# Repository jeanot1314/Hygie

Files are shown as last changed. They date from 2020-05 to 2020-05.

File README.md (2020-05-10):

# Hygie
A device to better follow your body's reactions. Hygie helps you to understand the evolution of symptoms that can affect you on daily basis

Created by Jean Perardel

Full Tutoriel on [Hackster](https://www.hackster.io/jeanperardel/hygie-better-follow-and-understand-your-menopause-fa8663)

Presentation Video on [Lab_1314](https://www.youtube.com/watch?v=uz1osdS2IEg)

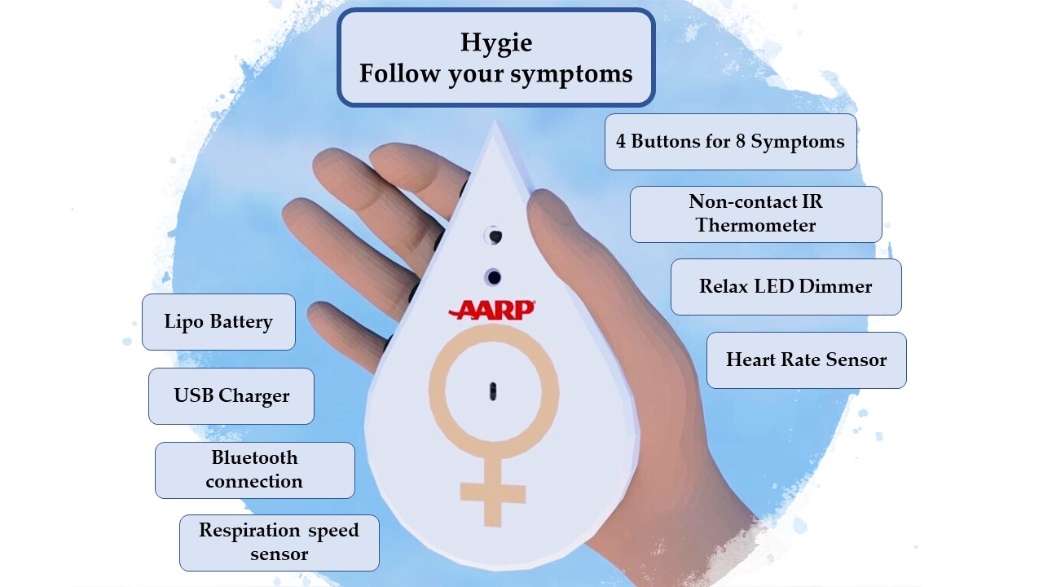
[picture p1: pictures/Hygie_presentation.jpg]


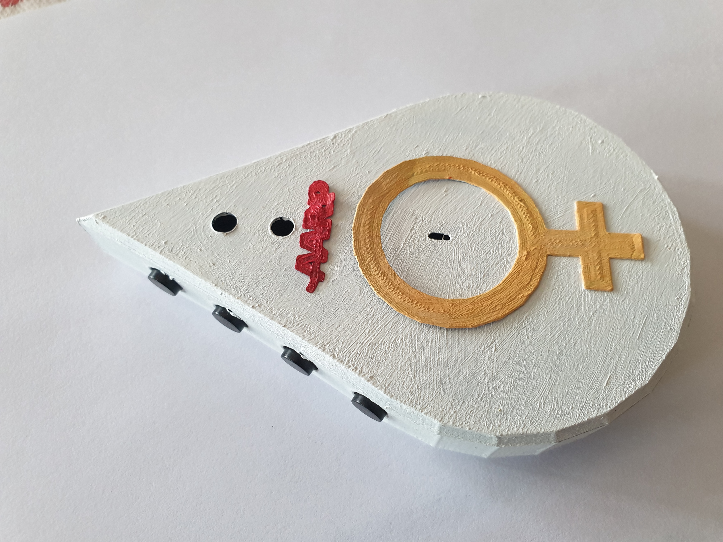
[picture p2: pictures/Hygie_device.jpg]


## Storie

The Hygie project has been designed to help women listen to and follow their bodies during this complicated period. To do this, it offers a simple and evolving interface that allows the different symptoms to be traced over time. The small device can easily fit into a coat pocket or handbag to accompany you discreetly everywhere.

Hygieia (Hygie in French) was one of the daughters of the God of medecine Asclepius in the Greek mythology. she was the goddess/personification of health.

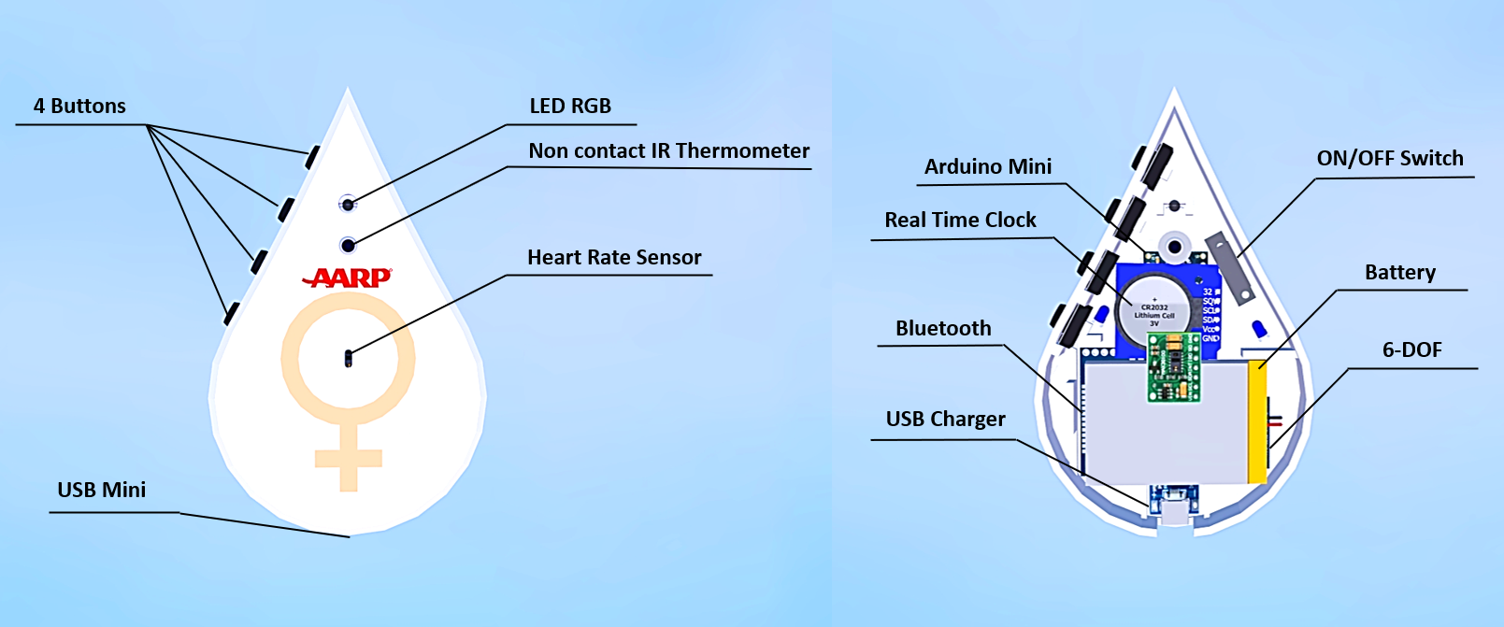
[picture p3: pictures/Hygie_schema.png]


The 4 buttons on the top allow you to trace the symptoms over time. Each of them must be associated with one (single click) or two (double click) symptoms according to the need and therefore recurrence for its user.

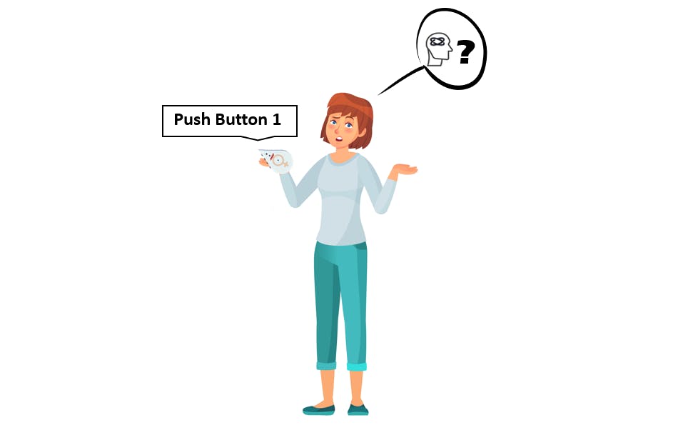
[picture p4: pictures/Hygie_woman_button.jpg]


Here is a configuration example :

Button 1 (single click) : Hot Flashes

Button 1 (double click) : Fatigue

Button 2 (single click) : Hair Loss

Button 2 (double click) : Incontinence

Button 3 (single click) : Change in odor

Button 4 (single click) : Mood Swings

Pressing these buttons at the onset of symptoms will allow you to trace the event over time and better understand their recurrence. Using Hygie for a period of time will thus generate graphs on the mobile application.

These data are also associated in tabular form with simple interpretations such as "The phenomenon of fatigue is particularly present after a meal" or "Gum problems" are often associated with "Breast Soreness".

## Build the device

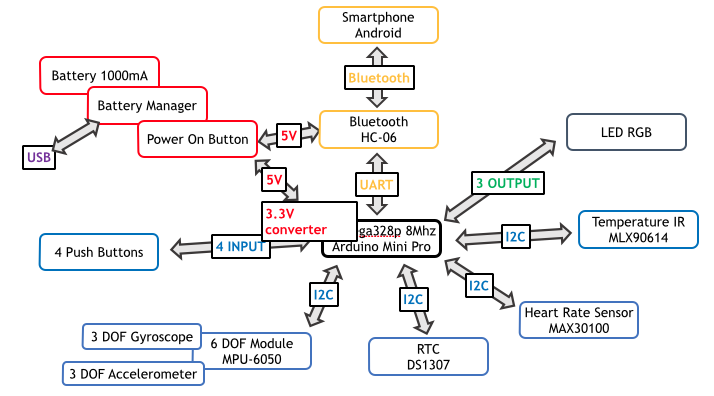
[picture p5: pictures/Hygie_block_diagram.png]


## Hardware

Image of Pi

The most important thing to remember here is that almost whole the system works in 3.3V. This forced me to carefully select the components (at first I wanted to use WS2812 RGB LEDs, but they are rather unstable in 3.3V so I had to remove them... too bad for the color rendering!).

At first, I thought the 3.6V Bluetooth would work on the 3.7V battery, but it seemed unstable... So I had to add a BOOST at the end to power only this part with 5V and step down everything else with the embedded regulator on the Arduino Pro Mini. I will probably change the Bluetooth board on the next version to remove the BOOST and have the all system working at 3.3V. This will also be a good occasion to move to BLE.

Another interesting part will be to develop small boards with MOSFETs to cut the power supply of unused modules. Indeed, this system uses some functionality only very occasionally. It is therefore a pity that a module like the MPU6050 consumes power all the time.

## Software

Arduino development on a Atmega328p target running at 8Mhz (FIO mode) 

Image of Pi

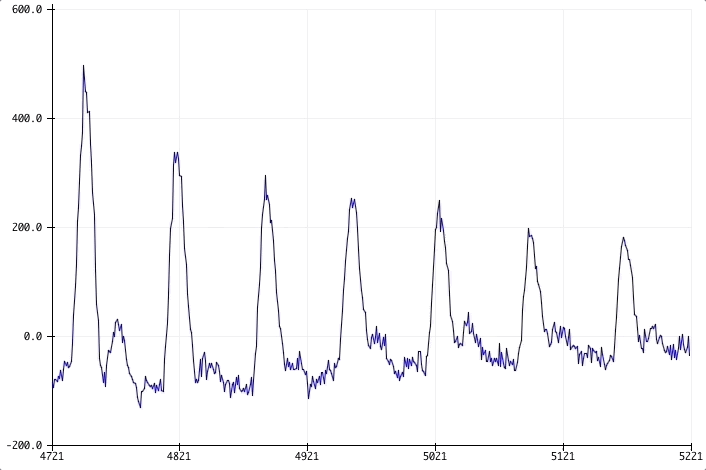
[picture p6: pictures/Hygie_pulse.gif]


## 3D design

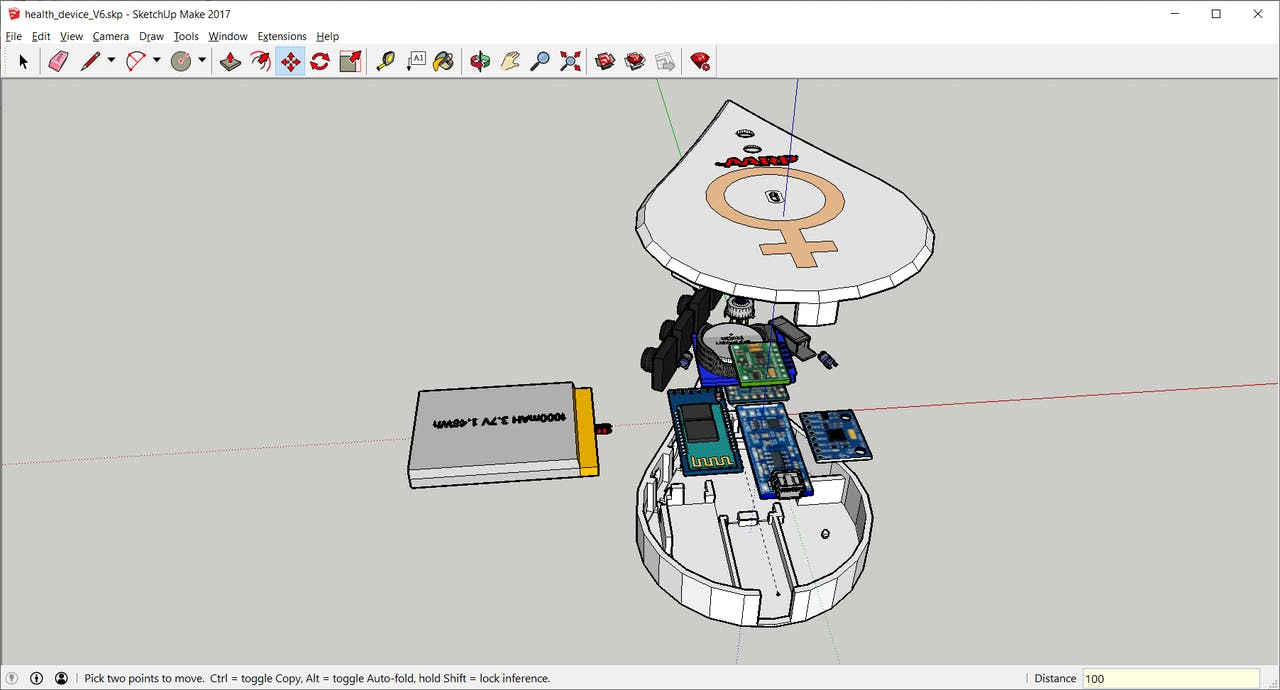
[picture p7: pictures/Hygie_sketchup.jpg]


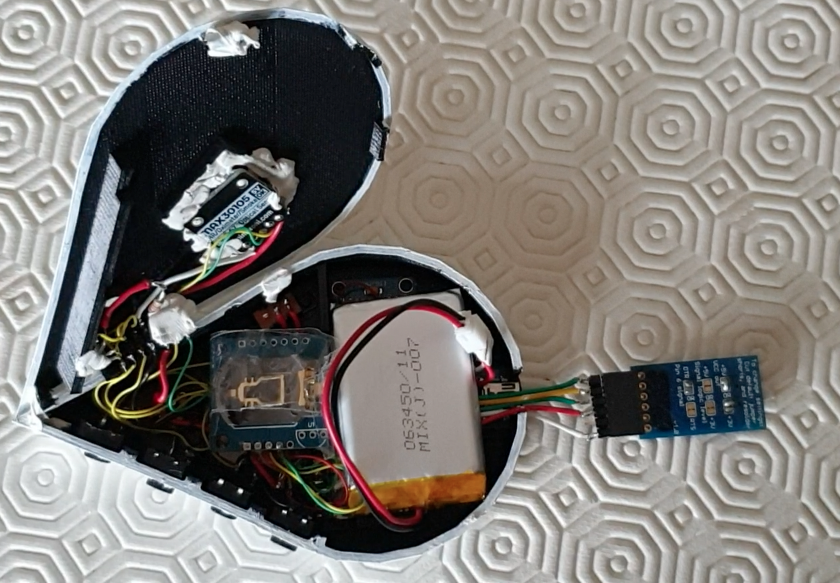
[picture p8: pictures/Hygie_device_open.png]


## Phone Graph (MIT App Inventor)

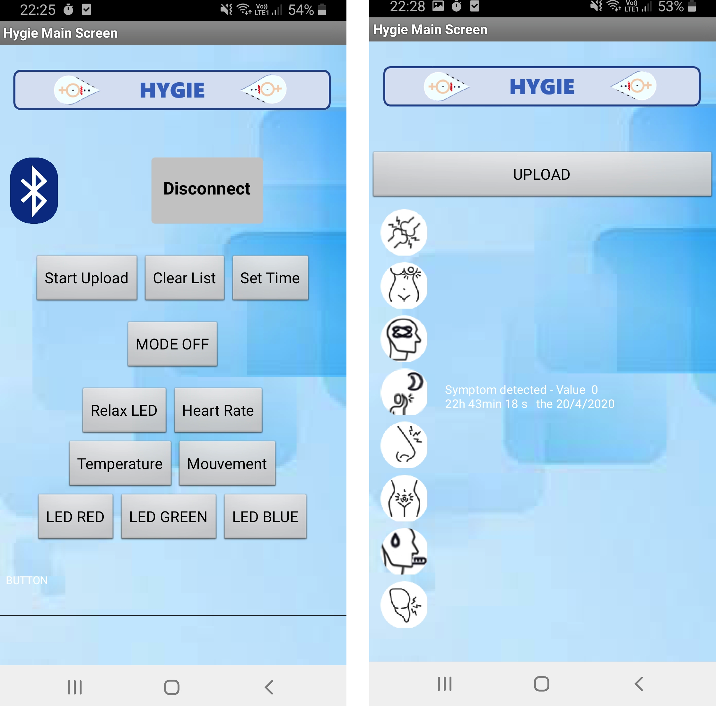
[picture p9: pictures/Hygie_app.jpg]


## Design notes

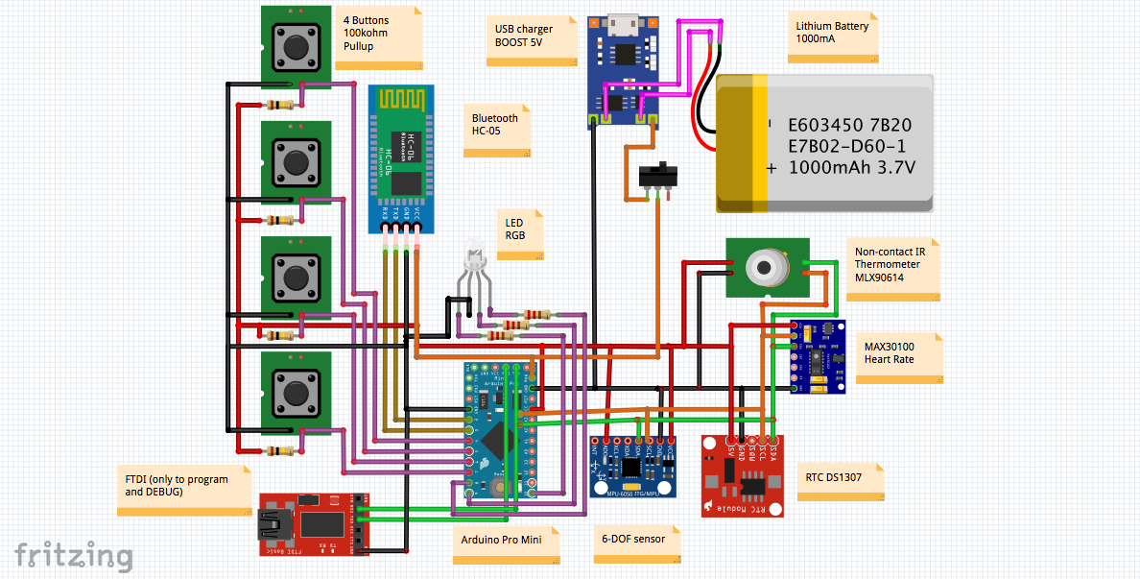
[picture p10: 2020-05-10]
pictures/Hygie_hardware.png

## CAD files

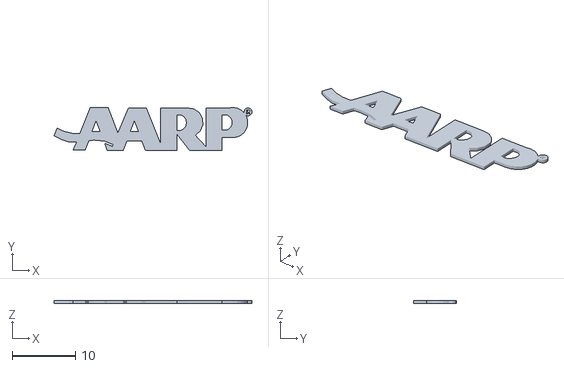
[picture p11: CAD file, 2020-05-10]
3D/health_device_V8_logo.stl
31.3 x 6.82 x 0.4

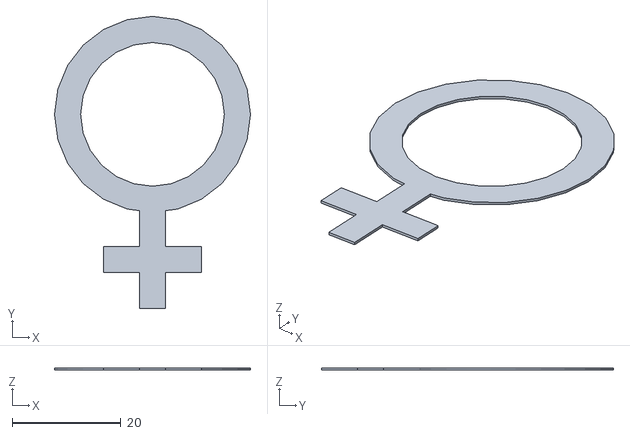
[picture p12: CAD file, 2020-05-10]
3D/health_device_V8_woman.stl
36.0 x 53.7 x 0.4

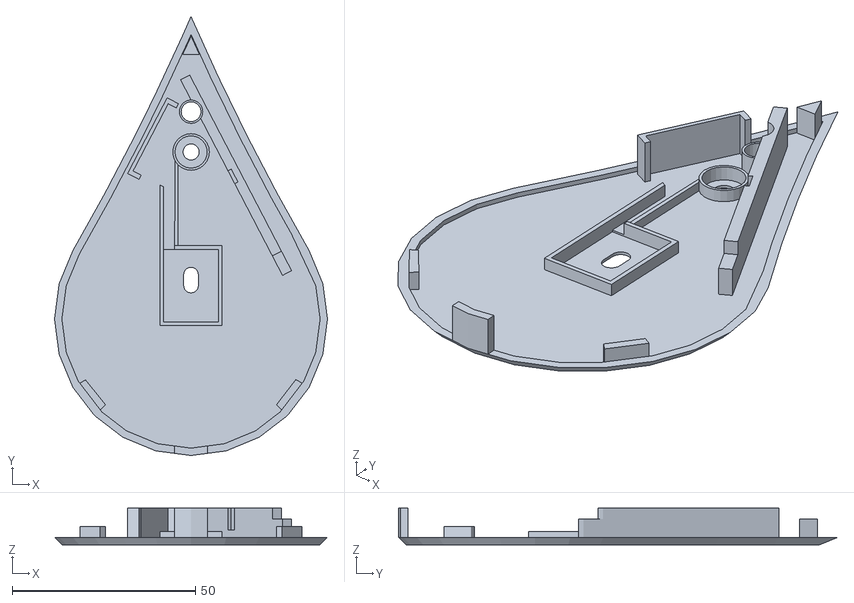
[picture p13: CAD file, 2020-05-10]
3D/health_device_V8_TOP.stl
74.6 x 119.9 x 10.0

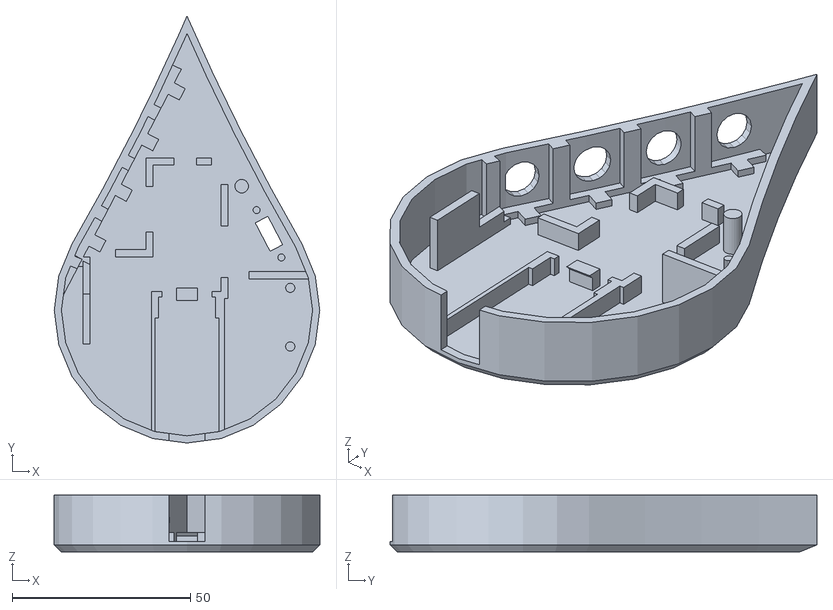
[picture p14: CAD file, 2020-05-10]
3D/health_device_V8.stl
74.6 x 119.9 x 16.0

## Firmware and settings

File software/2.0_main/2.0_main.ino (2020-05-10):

/*
 * Arduino code made by Jean Perardel
 * Project Hygie
 * 
 * 04 mai 2020
 */


#include <Wire.h>
#include <avr/interrupt.h>
#include <avr/pgmspace.h>
#include <SoftwareSerial.h>
#include <Adafruit_MLX90614.h>
// Temporary replacement from MAX30100 to MAX30105 because of supply
#include "MAX30100.h"
//#include "MAX30105.h"
#include "heartRate.h"
#include "RTCDS1307.h"
#include <EEPROM.h>

// MPU6050 6-DOF Sensor
#define MPU_ADDR 0x69
#define MEM_START_ADDR 0x6E
#define MEM_R_W 0x6F

// EEPROM cluster definition
#define EEPROM_CLUSTER_SIZE 8

// BLUETOOTH BUFFER SIZE
#define BLUETOOTH_BUFFER_SIZE 32

// define the time (in loop) necessary to consider a short and a long push button
#define Min_Time_Short_Push_Button 2
#define Min_Time_Long_Push_Button 15

// Reset the main counter at :
#define MAX_COUNTER 0xFFFF

// Definition of pseudo real time. Frequency will define the number of time the program
//enter the function on MAX_COUNTER number
#define Buttons_FREQUENCY 128
#define Buttons_FREQUENCY_READ_PER_CYCLE cpt%((MAX_COUNTER/Buttons_FREQUENCY)+1)
#define MAX30100_FREQUENCY 256
#define MAX30100_FREQUENCY_READ_PER_CYCLE cpt%((MAX_COUNTER/MAX30100_FREQUENCY)+1)
#define MLX90614_FREQUENCY 1
#define MLX90614_FREQUENCY_READ_PER_CYCLE cpt%((MAX_COUNTER/MLX90614_FREQUENCY)+1)
#define MPU6050_FREQUENCY 128
#define MPU6050_FREQUENCY_READ_PER_CYCLE cpt%((MAX_COUNTER/MPU6050_FREQUENCY)+1)
#define DS1307_FREQUENCY 1
#define DS1307_FREQUENCY_READ_PER_CYCLE cpt%((MAX_COUNTER/DS1307_FREQUENCY)+1)
#define HC06_FREQUENCY 128
#define HC06_FREQUENCY_READ_PER_CYCLE cpt%((MAX_COUNTER/HC06_FREQUENCY)+1)
#define Serial_FREQUENCY 128
#define Serial_FREQUENCY_READ_PER_CYCLE cpt%((MAX_COUNTER/Serial_FREQUENCY)+1)
#define DimLED_FREQUENCY 64
#define DimLED_FREQUENCY_READ_PER_CYCLE cpt%((MAX_COUNTER/DimLED_FREQUENCY)+1)
#define DebugLED_FREQUENCY 1
#define DebugLED_FREQUENCY_READ_PER_CYCLE cpt%((MAX_COUNTER/DebugLED_FREQUENCY)+1)
#define LEDPushButton_FREQUENCY 16
#define LEDPushButton_FREQUENCY_READ_PER_CYCLE cpt%((MAX_COUNTER/LEDPushButton_FREQUENCY)+1)

//----------------------- Variable for MPU6050 6-DOF Sensor-----------------------------
long lastRead = 0;
byte processed_packet[8];
byte received_packet[50];
byte temp = 0;
byte fifoCountL = 0;
byte fifoCountL2 = 0;
byte packetCount = 0x00;
boolean longPacket = false;
boolean firstPacket = true;
float q[4];

//This 3D array contains the default DMP memory bank binary that gets loaded during initialization.
//In the Invensense UC3-A3 firmware this is uploaded in 128 byte tranmissions, but the Arduino Wire
//library only supports 32 byte transmissions, including the register address to which you're writing,
//so I broke it up into 16 byte transmission payloads which are sent in the dmp_init() function below.
//
//This was reconstructed from observed I2C traffic generated by the UC3-A3 demo code, and not extracted
//directly from that code. That is true of all transmissions in this sketch, and any documentation has
//been added after the fact by referencing the Invensense code.

// this tab takes 6% of memory program storage 
unsigned const char dmpMem[8][16][16] PROGMEM = {
  {
    {0xFB, 0x00, 0x00, 0x3E, 0x00, 0x0B, 0x00, 0x36, 0x00, 0x01, 0x00, 0x02, 0x00, 0x03, 0x00, 0x00},
    {0x00, 0x65, 0x00, 0x54, 0xFF, 0xEF, 0x00, 0x00, 0xFA, 0x80, 0x00, 0x0B, 0x12, 0x82, 0x00, 0x01},
    {0x00, 0x02, 0x00, 0x00, 0x00, 0x00, 0x00, 0x00, 0x00, 0x00, 0x00, 0x00, 0x00, 0x00, 0x00, 0x00},
    {0x00, 0x28, 0x00, 0x00, 0xFF, 0xFF, 0x45, 0x81, 0xFF, 0xFF, 0xFA, 0x72, 0x00, 0x00, 0x00, 0x00},
    {0x00, 0x00, 0x03, 0xE8, 0x00, 0x00, 0x00, 0x01, 0x00, 0x01, 0x7F, 0xFF, 0xFF, 0xFE, 0x80, 0x01},
    {0x00, 0x1B, 0x00, 0x00, 0x00, 0x00, 0x00, 0x00, 0x00, 0x00, 0x00, 0x00, 0x00, 0x00, 0x00, 0x00},
    {0x00, 0x3E, 0x03, 0x30, 0x40, 0x00, 0x00, 0x00, 0x02, 0xCA, 0xE3, 0x09, 0x3E, 0x80, 0x00, 0x00},
    {0x20, 0x00, 0x00, 0x00, 0x00, 0x00, 0x00, 0x00, 0x40, 0x00, 0x00, 0x00, 0x60, 0x00, 0x00, 0x00},
    {0x41, 0xFF, 0x00, 0x00, 0x00, 0x00, 0x0B, 0x2A, 0x00, 0x00, 0x16, 0x55, 0x00, 0x00, 0x21, 0x82},
    {0xFD, 0x87, 0x26, 0x50, 0xFD, 0x80, 0x00, 0x00, 0x00, 0x1F, 0x00, 0x00, 0x00, 0x05, 0x80, 0x00},
    {0x00, 0x00, 0x00, 0x00, 0x00, 0x01, 0x00, 0x00, 0x00, 0x02, 0x00, 0x00, 0x00, 0x03, 0x00, 0x00},
    {0x40, 0x00, 0x00, 0x00, 0x00, 0x00, 0x04, 0x6F, 0x00, 0x02, 0x65, 0x32, 0x00, 0x00, 0x5E, 0xC0},
    {0x40, 0x00, 0x00, 0x00, 0x00, 0x00, 0x00, 0x00, 0x00, 0x00, 0x00, 0x00, 0x00, 0x00, 0x00, 0x00},
    {0xFB, 0x8C, 0x6F, 0x5D, 0xFD, 0x5D, 0x08, 0xD9, 0x00, 0x7C, 0x73, 0x3B, 0x00, 0x6C, 0x12, 0xCC},
    {0x32, 0x00, 0x13, 0x9D, 0x32, 0x00, 0xD0, 0xD6, 0x32, 0x00, 0x08, 0x00, 0x40, 0x00, 0x01, 0xF4},
    {0xFF, 0xE6, 0x80, 0x79, 0x02, 0x00, 0x00, 0x00, 0x00, 0x00, 0xD0, 0xD6, 0x00, 0x00, 0x27, 0x10}
  },
  {
    {0xFB, 0x00, 0x00, 0x00, 0x40, 0x00, 0x00, 0x00, 0x00, 0x00, 0x00, 0x00, 0x00, 0x00, 0x00, 0x00},
    {0x00, 0x00, 0x00, 0x01, 0x00, 0x00, 0x00, 0x00, 0x00, 0x00, 0x01, 0x00, 0x01, 0x00, 0x00, 0x00},
    {0x00, 0x00, 0xFA, 0x36, 0xFF, 0xBC, 0x30, 0x8E, 0x00, 0x05, 0xFB, 0xF0, 0xFF, 0xD9, 0x5B, 0xC8},
    {0xFF, 0xD0, 0x9A, 0xBE, 0x00, 0x00, 0x10, 0xA9, 0xFF, 0xF4, 0x1E, 0xB2, 0x00, 0xCE, 0xBB, 0xF7},
    {0x00, 0x00, 0x00, 0x01, 0x00, 0x00, 0x00, 0x04, 0x00, 0x02, 0x00, 0x02, 0x02, 0x00, 0x00, 0x0C},
    {0xFF, 0xC2, 0x80, 0x00, 0x00, 0x01, 0x80, 0x00, 0x00, 0xCF, 0x80, 0x00, 0x40, 0x00, 0x00, 0x00},
    {0x00, 0x00, 0x00, 0x01, 0x00, 0x00, 0x00, 0x00, 0x00, 0x00, 0x06, 0x00, 0x00, 0x00, 0x00, 0x14},
    {0x00, 0x00, 0x00, 0x00, 0x00, 0x00, 0x00, 0x00, 0x00, 0x00, 0x00, 0x00, 0x00, 0x00, 0x00, 0x00},
    {0x00, 0x00, 0x00, 0x00, 0x00, 0x00, 0x00, 0x00, 0x00, 0x00, 0x00, 0x00, 0x00, 0x00, 0x00, 0x00},
    {0x00, 0x00, 0x00, 0x00, 0x00, 0x00, 0x00, 0x00, 0x00, 0x00, 0x00, 0x00, 0x00, 0x00, 0x00, 0x00},
    {0x00, 0x00, 0x00, 0x00, 0x03, 0x3F, 0x68, 0xB6, 0x79, 0x35, 0x28, 0xBC, 0xC6, 0x7E, 0xD1, 0x6C},
    {0x80, 0x00, 0x00, 0x00, 0x40, 0x00, 0x00, 0x00, 0x00, 0x00, 0xB2, 0x6A, 0x00, 0x00, 0x00, 0x00},
    {0x00, 0x00, 0x00, 0x00, 0x00, 0x00, 0x00, 0x00, 0x00, 0x00, 0x3F, 0xF0, 0x00, 0x00, 0x00, 0x30},
    {0x00, 0x00, 0x00, 0x00, 0x00, 0x00, 0x00, 0x00, 0x00, 0x00, 0x00, 0x00, 0x00, 0x00, 0x00, 0x00},
    {0x00, 0x00, 0x00, 0x00, 0x00, 0x00, 0x00, 0x00, 0x00, 0x00, 0x00, 0x00, 0x00, 0x00, 0x00, 0x00},
    {0x00, 0x00, 0x25, 0x4D, 0x00, 0x2F, 0x70, 0x6D, 0x00, 0x00, 0x05, 0xAE, 0x00, 0x0C, 0x02, 0xD0}
  },
  {
    {0x00, 0x00, 0x00, 0x00, 0x00, 0x65, 0x00, 0x54, 0xFF, 0xEF, 0x00, 0x00, 0x00, 0x00, 0x00, 0x00},
    {0x00, 0x00, 0x01, 0x00, 0x00, 0x44, 0x00, 0x00, 0x00, 0x00, 0x0C, 0x00, 0x00, 0x00, 0x01, 0x00},
    {0x00, 0x00, 0x00, 0x00, 0x00, 0x65, 0x00, 0x00, 0x00, 0x54, 0x00, 0x00, 0xFF, 0xEF, 0x00, 0x00},
    {0x00, 0x00, 0x00, 0x00, 0x00, 0x00, 0x00, 0x00, 0x00, 0x00, 0x00, 0x00, 0x00, 0x00, 0x00, 0x00},
    {0x40, 0x00, 0x00, 0x00, 0x00, 0x00, 0x00, 0x00, 0x00, 0x00, 0x00, 0x00, 0x00, 0x00, 0x00, 0x00},
    {0x40, 0x00, 0x00, 0x00, 0x00, 0x00, 0x00, 0x00, 0x00, 0x00, 0x00, 0x00, 0x00, 0x00, 0x00, 0x00},
    {0x00, 0x00, 0x00, 0x01, 0x00, 0x00, 0x00, 0x02, 0x00, 0x00, 0x00, 0x00, 0x00, 0x00, 0x00, 0x00},
    {0x00, 0x00, 0x00, 0x00, 0x00, 0x00, 0x00, 0x00, 0x00, 0x00, 0x00, 0x00, 0x00, 0x00, 0x00, 0x00},
    {0x00, 0x00, 0x00, 0x00, 0x00, 0x00, 0x00, 0x00, 0x00, 0x00, 0x00, 0x00, 0x00, 0x00, 0x00, 0x00},
    {0x00, 0x1B, 0x00, 0x00, 0x00, 0x00, 0x00, 0x00, 0x00, 0x00, 0x00, 0x00, 0x00, 0x00, 0x00, 0x00},
    {0x00, 0x00, 0x00, 0x00, 0x00, 0x00, 0x00, 0x00, 0x00, 0x00, 0x00, 0x00, 0x00, 0x00, 0x00, 0x00},
    {0x00, 0x00, 0x00, 0x00, 0x00, 0x00, 0x00, 0x00, 0x00, 0x00, 0x00, 0x00, 0x40, 0x00, 0x00, 0x00},
    {0x00, 0x1B, 0x00, 0x00, 0x00, 0x00, 0x00, 0x00, 0x00, 0x00, 0x00, 0x00, 0x00, 0x00, 0x00, 0x00},
    {0x00, 0x00, 0x00, 0x00, 0x00, 0x00, 0x00, 0x00, 0x00, 0x00, 0x00, 0x00, 0x00, 0x00, 0x00, 0x00},
    {0x00, 0x00, 0x00, 0x00, 0x00, 0x00, 0x00, 0x00, 0x00, 0x00, 0x00, 0x00, 0x00, 0x00, 0x00, 0x00},
    {0x00, 0x00, 0x00, 0x00, 0x00, 0x00, 0x00, 0x00, 0x00, 0x00, 0x00, 0x00, 0x00, 0x00, 0x00, 0x00}
  },
  {
    {0xD8, 0xDC, 0xBA, 0xA2, 0xF1, 0xDE, 0xB2, 0xB8, 0xB4, 0xA8, 0x81, 0x91, 0xF7, 0x4A, 0x90, 0x7F},
    {0x91, 0x6A, 0xF3, 0xF9, 0xDB, 0xA8, 0xF9, 0xB0, 0xBA, 0xA0, 0x80, 0xF2, 0xCE, 0x81, 0xF3, 0xC2},
    {0xF1, 0xC1, 0xF2, 0xC3, 0xF3, 0xCC, 0xA2, 0xB2, 0x80, 0xF1, 0xC6, 0xD8, 0x80, 0xBA, 0xA7, 0xDF},
    {0xDF, 0xDF, 0xF2, 0xA7, 0xC3, 0xCB, 0xC5, 0xB6, 0xF0, 0x87, 0xA2, 0x94, 0x24, 0x48, 0x70, 0x3C},
    {0x95, 0x40, 0x68, 0x34, 0x58, 0x9B, 0x78, 0xA2, 0xF1, 0x83, 0x92, 0x2D, 0x55, 0x7D, 0xD8, 0xB1},
    {0xB4, 0xB8, 0xA1, 0xD0, 0x91, 0x80, 0xF2, 0x70, 0xF3, 0x70, 0xF2, 0x7C, 0x80, 0xA8, 0xF1, 0x01},
    {0xB0, 0x98, 0x87, 0xD9, 0x43, 0xD8, 0x86, 0xC9, 0x88, 0xBA, 0xA1, 0xF2, 0x0E, 0xB8, 0x97, 0x80},
    {0xF1, 0xA9, 0xDF, 0xDF, 0xDF, 0xAA, 0xDF, 0xDF, 0xDF, 0xF2, 0xAA, 0xC5, 0xCD, 0xC7, 0xA9, 0x0C},
    {0xC9, 0x2C, 0x97, 0x97, 0x97, 0x97, 0xF1, 0xA9, 0x89, 0x26, 0x46, 0x66, 0xB0, 0xB4, 0xBA, 0x80},
    {0xAC, 0xDE, 0xF2, 0xCA, 0xF1, 0xB2, 0x8C, 0x02, 0xA9, 0xB6, 0x98, 0x00, 0x89, 0x0E, 0x16, 0x1E},
    {0xB8, 0xA9, 0xB4, 0x99, 0x2C, 0x54, 0x7C, 0xB0, 0x8A, 0xA8, 0x96, 0x36, 0x56, 0x76, 0xF1, 0xB9},
    {0xAF, 0xB4, 0xB0, 0x83, 0xC0, 0xB8, 0xA8, 0x97, 0x11, 0xB1, 0x8F, 0x98, 0xB9, 0xAF, 0xF0, 0x24},
    {0x08, 0x44, 0x10, 0x64, 0x18, 0xF1, 0xA3, 0x29, 0x55, 0x7D, 0xAF, 0x83, 0xB5, 0x93, 0xAF, 0xF0},
    {0x00, 0x28, 0x50, 0xF1, 0xA3, 0x86, 0x9F, 0x61, 0xA6, 0xDA, 0xDE, 0xDF, 0xD9, 0xFA, 0xA3, 0x86},
    {0x96, 0xDB, 0x31, 0xA6, 0xD9, 0xF8, 0xDF, 0xBA, 0xA6, 0x8F, 0xC2, 0xC5, 0xC7, 0xB2, 0x8C, 0xC1},
    {0xB8, 0xA2, 0xDF, 0xDF, 0xDF, 0xA3, 0xDF, 0xDF, 0xDF, 0xD8, 0xD8, 0xF1, 0xB8, 0xA8, 0xB2, 0x86}
  },
  {
    {0xB4, 0x98, 0x0D, 0x35, 0x5D, 0xB8, 0xAA, 0x98, 0xB0, 0x87, 0x2D, 0x35, 0x3D, 0xB2, 0xB6, 0xBA},
    {0xAF, 0x8C, 0x96, 0x19, 0x8F, 0x9F, 0xA7, 0x0E, 0x16, 0x1E, 0xB4, 0x9A, 0xB8, 0xAA, 0x87, 0x2C},
    {0x54, 0x7C, 0xB9, 0xA3, 0xDE, 0xDF, 0xDF, 0xA3, 0xB1, 0x80, 0xF2, 0xC4, 0xCD, 0xC9, 0xF1, 0xB8},
    {0xA9, 0xB4, 0x99, 0x83, 0x0D, 0x35, 0x5D, 0x89, 0xB9, 0xA3, 0x2D, 0x55, 0x7D, 0xB5, 0x93, 0xA3},
    {0x0E, 0x16, 0x1E, 0xA9, 0x2C, 0x54, 0x7C, 0xB8, 0xB4, 0xB0, 0xF1, 0x97, 0x83, 0xA8, 0x11, 0x84},
    {0xA5, 0x09, 0x98, 0xA3, 0x83, 0xF0, 0xDA, 0x24, 0x08, 0x44, 0x10, 0x64, 0x18, 0xD8, 0xF1, 0xA5},
    {0x29, 0x55, 0x7D, 0xA5, 0x85, 0x95, 0x02, 0x1A, 0x2E, 0x3A, 0x56, 0x5A, 0x40, 0x48, 0xF9, 0xF3},
    {0xA3, 0xD9, 0xF8, 0xF0, 0x98, 0x83, 0x24, 0x08, 0x44, 0x10, 0x64, 0x18, 0x97, 0x82, 0xA8, 0xF1},
    {0x11, 0xF0, 0x98, 0xA2, 0x24, 0x08, 0x44, 0x10, 0x64, 0x18, 0xDA, 0xF3, 0xDE, 0xD8, 0x83, 0xA5},
    {0x94, 0x01, 0xD9, 0xA3, 0x02, 0xF1, 0xA2, 0xC3, 0xC5, 0xC7, 0xD8, 0xF1, 0x84, 0x92, 0xA2, 0x4D},
    {0xDA, 0x2A, 0xD8, 0x48, 0x69, 0xD9, 0x2A, 0xD8, 0x68, 0x55, 0xDA, 0x32, 0xD8, 0x50, 0x71, 0xD9},
    {0x32, 0xD8, 0x70, 0x5D, 0xDA, 0x3A, 0xD8, 0x58, 0x79, 0xD9, 0x3A, 0xD8, 0x78, 0x93, 0xA3, 0x4D},
    {0xDA, 0x2A, 0xD8, 0x48, 0x69, 0xD9, 0x2A, 0xD8, 0x68, 0x55, 0xDA, 0x32, 0xD8, 0x50, 0x71, 0xD9},
    {0x32, 0xD8, 0x70, 0x5D, 0xDA, 0x3A, 0xD8, 0x58, 0x79, 0xD9, 0x3A, 0xD8, 0x78, 0xA8, 0x8A, 0x9A},
    {0xF0, 0x28, 0x50, 0x78, 0x9E, 0xF3, 0x88, 0x18, 0xF1, 0x9F, 0x1D, 0x98, 0xA8, 0xD9, 0x08, 0xD8},
    {0xC8, 0x9F, 0x12, 0x9E, 0xF3, 0x15, 0xA8, 0xDA, 0x12, 0x10, 0xD8, 0xF1, 0xAF, 0xC8, 0x97, 0x87}
  },
  {
    {0x34, 0xB5, 0xB9, 0x94, 0xA4, 0x21, 0xF3, 0xD9, 0x22, 0xD8, 0xF2, 0x2D, 0xF3, 0xD9, 0x2A, 0xD8},
    {0xF2, 0x35, 0xF3, 0xD9, 0x32, 0xD8, 0x81, 0xA4, 0x60, 0x60, 0x61, 0xD9, 0x61, 0xD8, 0x6C, 0x68},
    {0x69, 0xD9, 0x69, 0xD8, 0x74, 0x70, 0x71, 0xD9, 0x71, 0xD8, 0xB1, 0xA3, 0x84, 0x19, 0x3D, 0x5D},
    {0xA3, 0x83, 0x1A, 0x3E, 0x5E, 0x93, 0x10, 0x30, 0x81, 0x10, 0x11, 0xB8, 0xB0, 0xAF, 0x8F, 0x94},
    {0xF2, 0xDA, 0x3E, 0xD8, 0xB4, 0x9A, 0xA8, 0x87, 0x29, 0xDA, 0xF8, 0xD8, 0x87, 0x9A, 0x35, 0xDA},
    {0xF8, 0xD8, 0x87, 0x9A, 0x3D, 0xDA, 0xF8, 0xD8, 0xB1, 0xB9, 0xA4, 0x98, 0x85, 0x02, 0x2E, 0x56},
    {0xA5, 0x81, 0x00, 0x0C, 0x14, 0xA3, 0x97, 0xB0, 0x8A, 0xF1, 0x2D, 0xD9, 0x28, 0xD8, 0x4D, 0xD9},
    {0x48, 0xD8, 0x6D, 0xD9, 0x68, 0xD8, 0xB1, 0x84, 0x0D, 0xDA, 0x0E, 0xD8, 0xA3, 0x29, 0x83, 0xDA},
    {0x2C, 0x0E, 0xD8, 0xA3, 0x84, 0x49, 0x83, 0xDA, 0x2C, 0x4C, 0x0E, 0xD8, 0xB8, 0xB0, 0xA8, 0x8A},
    {0x9A, 0xF5, 0x20, 0xAA, 0xDA, 0xDF, 0xD8, 0xA8, 0x40, 0xAA, 0xD0, 0xDA, 0xDE, 0xD8, 0xA8, 0x60},
    {0xAA, 0xDA, 0xD0, 0xDF, 0xD8, 0xF1, 0x97, 0x86, 0xA8, 0x31, 0x9B, 0x06, 0x99, 0x07, 0xAB, 0x97},
    {0x28, 0x88, 0x9B, 0xF0, 0x0C, 0x20, 0x14, 0x40, 0xB8, 0xB0, 0xB4, 0xA8, 0x8C, 0x9C, 0xF0, 0x04},
    {0x28, 0x51, 0x79, 0x1D, 0x30, 0x14, 0x38, 0xB2, 0x82, 0xAB, 0xD0, 0x98, 0x2C, 0x50, 0x50, 0x78},
    {0x78, 0x9B, 0xF1, 0x1A, 0xB0, 0xF0, 0x8A, 0x9C, 0xA8, 0x29, 0x51, 0x79, 0x8B, 0x29, 0x51, 0x79},
    {0x8A, 0x24, 0x70, 0x59, 0x8B, 0x20, 0x58, 0x71, 0x8A, 0x44, 0x69, 0x38, 0x8B, 0x39, 0x40, 0x68},
    {0x8A, 0x64, 0x48, 0x31, 0x8B, 0x30, 0x49, 0x60, 0xA5, 0x88, 0x20, 0x09, 0x71, 0x58, 0x44, 0x68}
  },
  {
    {0x11, 0x39, 0x64, 0x49, 0x30, 0x19, 0xF1, 0xAC, 0x00, 0x2C, 0x54, 0x7C, 0xF0, 0x8C, 0xA8, 0x04},
    {0x28, 0x50, 0x78, 0xF1, 0x88, 0x97, 0x26, 0xA8, 0x59, 0x98, 0xAC, 0x8C, 0x02, 0x26, 0x46, 0x66},
    {0xF0, 0x89, 0x9C, 0xA8, 0x29, 0x51, 0x79, 0x24, 0x70, 0x59, 0x44, 0x69, 0x38, 0x64, 0x48, 0x31},
    {0xA9, 0x88, 0x09, 0x20, 0x59, 0x70, 0xAB, 0x11, 0x38, 0x40, 0x69, 0xA8, 0x19, 0x31, 0x48, 0x60},
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
void loop() {

  // Button management
  if (Buttons_FREQUENCY_READ_PER_CYCLE == 0){Button_read();}  

  // LED DIMMER : MODE 1
  if (DimLED_FREQUENCY_READ_PER_CYCLE == 0 && device_MODE==1){
    if(!flag_init_LED_DIMMER){flag_init_LED_DIMMER=1;}
    DimLED_write();
  }

  // Heart rate : MODE 2
  if (MAX30100_FREQUENCY_READ_PER_CYCLE == 0 && device_MODE==2){
    if(!flag_init_MAX30105){ MAX30100_read();delay(10);flag_init_MAX30105=1;}
   
  }
  
  // Temperature : MODE 3
  if (MLX90614_FREQUENCY_READ_PER_CYCLE == 0 && device_MODE==3){
    if(!flag_init_MLX90614){
     //mlx.begin();
     Serial.println("START READING TEMPERATURE : ");
     digitalWrite(ledRGB_Red_Pin, LOW);
      flag_init_MLX90614=1;
   }
   //MLX90614_read();
  }
  
  // 6-DOF : MODE 4
  if (MPU6050_FREQUENCY_READ_PER_CYCLE == 0 && device_MODE==4){
    if(!flag_init_MPU6050){MPU6050_init();delay(10);flag_init_MPU6050=1;}
    MPU6050_read();
  }
 
  // Bluetooth read/write
  if (HC06_FREQUENCY_READ_PER_CYCLE == 0){HC06_readWrite();}
  // Serial read/write
  if (Serial_FREQUENCY_READ_PER_CYCLE == 0){Serial_readWrite();}
  // Blink DEBUG LED
  if (DebugLED_FREQUENCY_READ_PER_CYCLE == 0){DebugLED_write();}
  // Read Clock, print info
  if (DS1307_FREQUENCY_READ_PER_CYCLE == 0 && device_MODE==5){DebugINFO_write();}
  // Blink green LED when button press
  if (LEDPushButton_FREQUENCY_READ_PER_CYCLE == 0){
    if (cpt_LEDPushButton){
      cpt_LEDPushButton--;
      stop_LEDPushButton=1;
    }
    else if (stop_LEDPushButton){
      digitalWrite(ledRGB_Green_Pin, HIGH);
      stop_LEDPushButton=0;
    }  
  }
  
  // Set flags back to 0
  if (DebugLED_FREQUENCY_READ_PER_CYCLE == 0){
    if(device_MODE != 1 && flag_init_LED_DIMMER == 1){
      digitalWrite(ledRGB_Blue_Pin, HIGH);
      flag_init_LED_DIMMER=0;
    }
    if(device_MODE != 2 && flag_init_MAX30105 == 1){
      flag_init_MAX30105=0;
      MAX30100_init();
    }
    if(device_MODE != 3 && flag_init_MLX90614 == 1){
      digitalWrite(ledRGB_Red_Pin, HIGH);
      flag_init_MLX90614=0;
    }
    if(device_MODE != 4 && flag_init_MPU6050 == 1){
      flag_init_MPU6050=0;
    }
  }
  
  if(cpt == MAX_COUNTER){cpt=0;}
  else{cpt++;}
  
}

// --------------------General functions--------------------
void pin_init() {
  pinMode(ledRGB_Blue_Pin, OUTPUT);
  digitalWrite(ledRGB_Blue_Pin, HIGH);
  pinMode(ledRGB_Green_Pin, OUTPUT);
  digitalWrite(ledRGB_Green_Pin, HIGH);
  pinMode(ledRGB_Red_Pin, OUTPUT);
  digitalWrite(ledRGB_Red_Pin, HIGH);

  pinMode(ledDebug_Pin, OUTPUT);
  digitalWrite(ledDebug_Pin, LOW);
  
  pinMode(Button_1_Pin, INPUT);
  pinMode(Button_2_Pin, INPUT);
  pinMode(Button_3_Pin, INPUT);
  pinMode(Button_4_Pin, INPUT);
}

void DebugINFO_write() {
  Serial.print("SYSTEM INFO : ");
  uint8_t year, month, weekday, day, hour, minute, second;
  bool period = 0;  
  rtc.getDate(year, month, day, weekday);
  rtc.getTime(hour, minute, second, period);
  Serial.print(day, DEC);Serial.print("/");
  Serial.print(month);Serial.print("/");
  Serial.print(year + 2000, DEC);Serial.print("  ");
  Serial.print(hour, DEC);Serial.print(":");
  Serial.print(minute, DEC);Serial.print(":");
  Serial.print(second, DEC);Serial.print(" --- ");
  
  Serial.print("MODE=");Serial.print(device_MODE);Serial.print(" --- ");
  EEPROM_checkData();
  //Serial.println();
}

void DebugLED_write() {
  digitalWrite(ledDebug_Pin, !digitalRead(ledDebug_Pin));
}

// --------------------Buttons and mode management--------------------
void Button_read(){
  
  // --------------Button 1--------------
  int Button_Statut = 0;

  if (Button_1_press_cpt >= Min_Time_Short_Push_Button && Button_1_press_cpt < Min_Time_Long_Push_Button && (digitalRead(Button_1_Pin))==1){Button_Statut=1;}
  else if (Button_1_press_cpt >= Min_Time_Long_Push_Button && (digitalRead(Button_1_Pin))==1){Button_Statut=2;}
  
  if(Button_Statut == 1){
    if(double_click_Button_1_cpt > 0){
      Serial.print("Double Short Press Button 1  ");
      EEPROM_addValue(5, 0);
      Serial.println();
    }
    else{
      Serial.println("Short Press Button 1  ");
      EEPROM_addValue(1, 0);
      Serial.println();
    }
    Button_1_press++;
    device_MODE=0;
    Button_1_press_cpt=0;
    double_click_Button_1_cpt=20;
    //mode_init();
    cpt_LEDPushButton=0x01;
    digitalWrite(ledRGB_Green_Pin, LOW);
  }
  else if(Button_Statut == 2){
    Serial.println("Long Press Button 1");
    device_MODE=1;
    Button_1_press_cpt=0;
  }
  // Replace this call for Button press time debug
  //if((digitalRead(Button_1_Pin))==0){Button_1_press_cpt++;Serial.println(Button_1_press_cpt);}
  if((digitalRead(Button_1_Pin))==0){Button_1_press_cpt++;}
  else{
    Button_1_press_cpt=0;
    if(double_click_Button_1_cpt > 0){
      double_click_Button_1_cpt--;
    }  
  }

  // --------------Button 2--------------
  Button_Statut=0;
  if (Button_2_press_cpt >= Min_Time_Short_Push_Button && Button_2_press_cpt < Min_Time_Long_Push_Button && (digitalRead(Button_2_Pin))==1){Button_Statut=1;}
  else if (Button_2_press_cpt >= Min_Time_Long_Push_Button && (digitalRead(Button_2_Pin))==1){Button_Statut=2;}
  
  if(Button_Statut == 1){
    if(double_click_Button_2_cpt > 0){
      Serial.print("Double Short Press Button 2  ");
      EEPROM_addValue(6, 0);
      Serial.println();
    }
    else{
      Serial.print("Short Press Button 2  ");
      EEPROM_addValue(2, 0);
      Serial.println();
    }
    Button_2_press++;
    device_MODE=0;
    Button_2_press_cpt=0;
    double_click_Button_2_cpt=20;
    cpt_LEDPushButton=0x01;
    digitalWrite(ledRGB_Green_Pin, LOW);
  }
  else if(Button_Statut == 2){
    Serial.println("Long Press Button 2");
    device_MODE=2;
    Button_2_press_cpt=0;
  }
  if((digitalRead(Button_2_Pin))==0){Button_2_press_cpt++;}
  else{
    Button_2_press_cpt=0;
    if(double_click_Button_2_cpt > 0){
      double_click_Button_2_cpt--;
    }  
  }

  // --------------Button 3--------------
  Button_Statut=0;
  if (Button_3_press_cpt >= Min_Time_Short_Push_Button && Button_3_press_cpt < Min_Time_Long_Push_Button && (digitalRead(Button_3_Pin))==1){Button_Statut=1;}
  else if (Button_3_press_cpt >= Min_Time_Long_Push_Button && (digitalRead(Button_3_Pin))==1){Button_Statut=2;}
  
  if(Button_Statut == 1){
    if(double_click_Button_3_cpt > 0){
      Serial.print("Double Short Press Button 3  ");
      EEPROM_addValue(7, 0);
      Serial.println();
      }
    else{
      Serial.print("Short Press Button 3  ");
      EEPROM_addValue(3, 0);
      Serial.println();
    }
    Button_3_press++;
    device_MODE=0;
    Button_3_press_cpt=0;
    double_click_Button_3_cpt=20;
    cpt_LEDPushButton=0x01;
    digitalWrite(ledRGB_Green_Pin, LOW);
  }
  else if(Button_Statut == 2){
    Serial.println("Long Press Button 3");
    device_MODE=3;
    Button_3_press_cpt=0;
  }
  if((digitalRead(Button_3_Pin))==0){Button_3_press_cpt++;}
  else{
    Button_3_press_cpt=0;
    if(double_click_Button_3_cpt > 0){
      double_click_Button_3_cpt--;
    }      
  }

  // --------------Button 4--------------
  Button_Statut=0;
  if (Button_4_press_cpt >= Min_Time_Short_Push_Button && Button_4_press_cpt < Min_Time_Long_Push_Button && (digitalRead(Button_4_Pin))==1){Button_Statut=1;}
  else if (Button_4_press_cpt >= Min_Time_Long_Push_Button && (digitalRead(Button_4_Pin))==1){Button_Statut=2;}
  
  if(Button_Statut == 1){
    if(double_click_Button_4_cpt > 0){
      Serial.print("Double Short Press Button 4  ");
      EEPROM_addValue(8, 0);
      Serial.println();
      }
    else{
      Serial.print("Short Press Button 4  ");
      EEPROM_addValue(4, 0);
      Serial.println(); 
    }
    Button_4_press++;
    device_MODE=0;
    Button_4_press_cpt=0;
    double_click_Button_4_cpt=20;
    cpt_LEDPushButton=0x01;
    digitalWrite(ledRGB_Green_Pin, LOW);
  }
  else if(Button_Statut == 2){
    Serial.println("Long Press Button 4");
    device_MODE=4;
    Button_4_press_cpt=0;    
  }
  if((digitalRead(Button_4_Pin))==0){Button_4_press_cpt++;}
  else{
    Button_4_press_cpt=0;
    if(double_click_Button_4_cpt > 0){
      double_click_Button_4_cpt--;
    }  
  }
}

// --------------------Dimmer LED--------------------
void DimLED_write() {
    analogWrite(ledRGB_Blue_Pin, fadeValue);
    if(fadeDirection==0){fadeValue=fadeValue+8;}
    else if(fadeDirection==1){fadeValue=fadeValue-8;}
    if (fadeValue > 255 && fadeValue <= 0x7FFF){
      fadeDirection=1;
      fadeValue=255;
    }
    else if (fadeValue > 0x7FFF){
      fadeDirection=0;
      fadeValue=0;
    }
}
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

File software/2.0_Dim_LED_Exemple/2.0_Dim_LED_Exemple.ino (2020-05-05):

/*
  Fading

  This example shows how to fade an LED using the analogWrite() function.

  The circuit:
  - LED attached from digital pin 9 to ground.

  created 1 Nov 2008
  by David A. Mellis
  modified 30 Aug 2011
  by Tom Igoe

  This example code is in the public domain.

  http://www.arduino.cc/en/Tutorial/Fading
*/

int ledDim_Pin = 9;    // LED connected to digital pin 9
int ledDebug_Pin = 13;    // LED connected to digital pin 9

void setup() {
  // nothing happens in setup
}

void loop() {
  // fade in from min to max in increments of 5 points:
  for (int fadeValue = 0 ; fadeValue <= 255; fadeValue += 5) {
    // sets the value (range from 0 to 255):
    analogWrite(ledPin, fadeValue);
    // wait for 30 milliseconds to see the dimming effect
    delay(30);
  }

  // fade out from max to min in increments of 5 points:
  for (int fadeValue = 255 ; fadeValue >= 0; fadeValue -= 5) {
    // sets the value (range from 0 to 255):
    analogWrite(ledPin, fadeValue);
    // wait for 30 milliseconds to see the dimming effect
    delay(30);
  }
}

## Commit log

2020-05-10 Update 2.0_main.ino
    Change the Pulse sensor to MAX30100/MAX30102.
2020-05-10 Add 3D Print sketchup & Fritzing hardware
    [Hygie_Fritzing_Schematic.fzz, health_device_V8.stl, health_device_V8_TOP.stl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]
2020-05-10 Add few pictures of the device for readme
